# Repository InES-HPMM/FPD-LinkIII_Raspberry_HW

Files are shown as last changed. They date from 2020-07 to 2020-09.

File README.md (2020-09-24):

# FPD-LinkIII_Raspberry_HW

FPD-Link III Hardware compatible with Raspberry Pi Camera and Raspberry Pi CSI connector.

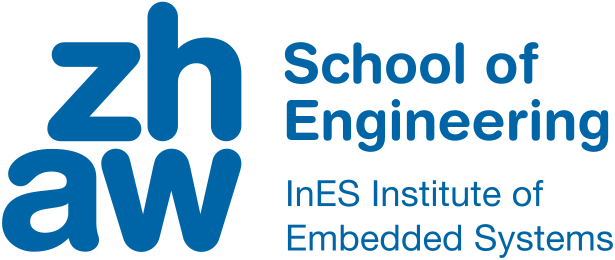
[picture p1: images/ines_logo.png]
(https://www.zhaw.ch/en/engineering/institutes-centres/ines/ "Homepage")


__The group High Performance Multimedia from the Institute of Embedded Systems associated with ZHAW School of Engineering proudly presents a TI FPD-Link III hardware compatible with the Raspberry Pi camera and the Raspberry Pi FFC (FPC, ZIF) camera connector.__

__Additionally we provide an open source driver for TI devices DS90UB954 paired with DS90UB953:__
<https://github.com/InES-HPMM/FPD-LinkIII_ds90ub95x>

> For recent news check out our [Blog](https://blog.zhaw.ch/high-performance/).

## Working Setup

### Overview

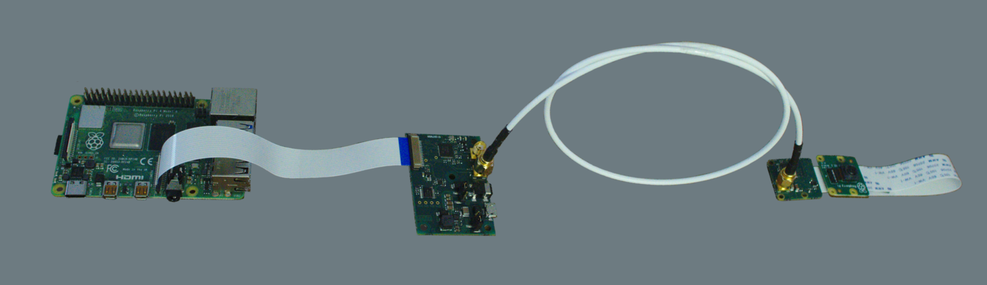
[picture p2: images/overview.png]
Overview


```ditaa
/-------------------\        /----------------------\        /--------------------\        /------------------\
| MIPI CSI RECEIVER |        | FPDLINK DESERIALIZER |        | FPDLINK SERIALIZER |        | MIPI CSI CAMERA  |
+-------------------+  CSI   +----------------------+        +--------------------+  CSI   +------------------+
|                   | <----- |                      |  Coax  |                    | <----- |                  |
| Raspberry Pi (4)  |  GPIO  | fpdlink2raspi        | <----> | piCam2fpdlink      |  GPIO  | Raspberry Pi     |
| Jetson Nano       | <----> | PCB                  |        | PCB                | <----> | Camera Module v2 |
| ...               |   I2C  | DS90UB954            |        | DS90UB953          |   I2C  |                  |
|                   | <----> |                      |        |                    | <----> |                  |
\-------------------/        \----------------------/        \--------------------/        \------------------/
```
 
### fpdlink2raspi PCB

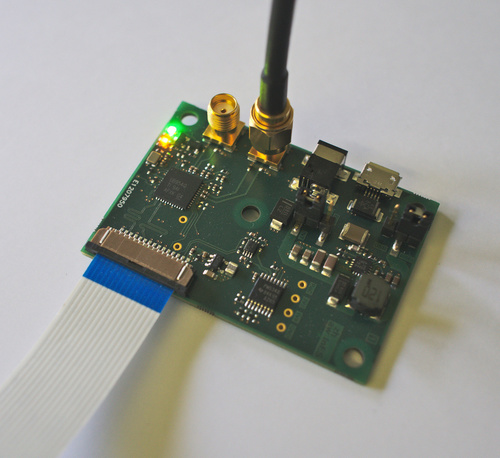
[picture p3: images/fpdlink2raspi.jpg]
fpdlink2raspi PCB

 
### piCam2fpdlink PCB

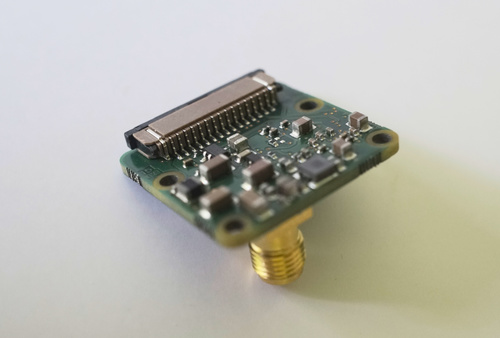
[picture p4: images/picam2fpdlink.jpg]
piCam2fpdlink PCB

 
### Raspberry Pi 4 with MIPI CSI connector

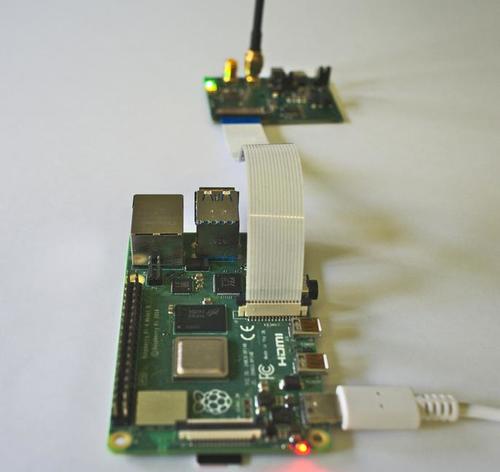
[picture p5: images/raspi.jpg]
RaspberryPi 4


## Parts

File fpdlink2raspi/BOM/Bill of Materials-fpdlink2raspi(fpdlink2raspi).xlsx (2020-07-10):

Name | Description | Designator | Quantity | LibRef | Supplier 1 | Supplier Part Number 1 | Manufacturer 1 | Manufacturer Part Number 1
100n | SMD 100 nF, 50V, X7R, 0402, 10% | C1, C3, C4, C5, C6, C8, C10, C12, C14, C20, C24, C30, C37, C38, C42, C53 | 16 | C0402_100N_X7R_50V_10PCT | Mouser | 81-GCM155R71H104KE2J | Murata | GCM155R71H104KE02J
10n | SMD 10 nF, 16V, X7R, 0402, 10% | C2 | 1 | C0402_010N_X7R_16V_10PCT | Mouser | 81-GRM36X103K16 | Murata | GRM155R71C103KA01D
10u | 10µF, 25V, +/-20%, X5R, 0603 | C7, C9, C11, C13, C23, C29, C51, C52 | 8 | C0603_010U_X5R_25V | Digi-Key | 490-7202-6-ND | Murata | GRM188R61E106MA73D
33n | SMD 33 nF, 50V, X7R, 0402, 10% | C15, C17, C36, C41 | 4 | C0402_033N_X7R_50V_10PCT | Digi-Key | 445-6896-1-ND | TDK | CGA2B3X7R1H333K050BB
15n | SMD 15 nF, 50V, X7R, 0402, 10% | C16, C18 | 2 | C0402_015N_X7R_50V_10PCT | Digi-Key | 445-6894-1-ND | TDK | CGA2B3X7R1H153K050BB
1u | SMD 1 µF, 35V, X5R, 0402, 10% | C19, C27 | 2 | C0402_001U_X5R_35V_10PCT | Digi-Key | 587-6008-1-ND | Taiyo Yuden | GMK105ABJ105KV-F
10n | SMD 10 nF, 50V, X7R, 0402, 10% | C21, C22, C25, C26, C28, C31, C32, C35, C40, C44, C46 | 11 | C0402_010N_X7R_50V_10PCT | Digi-Key | 490-4762-1-ND | Murata | GCM155R71H103KA55D
4u7 | 4.7µF, 25V, +/-10%, X5R, 0603 | C34, C39, C43, C45 | 4 | C0603_04U7_X5R_25V | Digi-Key | 490-7203-1-ND | Murata | GRM188R61E475KE11D
22u | 22µF ±20% 35V Ceramic Capacitor X5R 1206 (3216 Metric) | C47, C48 | 2 | C1206_022U_X5R_35V_20PCT | Digi-Key | 445-8045-1-ND | TDK | C3216X5R1V226M160AC
1u | 1µF ±10% 35V Ceramic Capacitor X7R 0805 (2012 Metric) | C49, C50 | 2 | C0805_001U_X7R_35V_10PCT | Digi-Key | 587-1438-1-ND | Taiyo Yuden | GMK212B7105KG-T
47n | 0.047µF ±10% 16V Ceramic Capacitor X7R 0402 (1005 Metric) | C54 | 1 | C0402_047N_X7R_16V_10PCT | Mouser | 81-GRM155R71C473KA01 | Murata | GRM155R71C473KA01D
3n9 | 3900pF ±5% 50V Ceramic Capacitor C0G, NP0 0603 (1608 Metric) | C55 | 1 | C0603_03N9_C0G_50V_5PCT | Digi-Key | 490-6387-1-ND | Murata | GRM1885C1H392JA01D
220n | 0.22µF ±5% 50V Ceramic Capacitor C0G, NP0 1812 (4532 Metric) | C56 | 1 | C1812_220N_C0G_50V_5PCT | Digi-Key | 445-7892-1-ND | TDK | CGA8R2C0G1H224J320KA
4u7 | SMD 4.7 µF, 10V, X5R, 0402, 20% | C57 | 1 | C0402_04U7_X5R_10V_20PCT | Mouser | 81-GRM155R61A475MEAD | Murata | GRM155R61A475MEAAD
22u | SMD 22 µF, 6.3V, X5R, 0603, 20% | C58 | 1 | C0603_022U_X5R_6V3_20PCT | Digi-Key | 490-13241-1-ND | Murata | GRM186R60J226ME15D
Green, 3.2 V, 140° | WL-SMCD SMD Mono-color Chip LED Diffused, size 0603, Green, 3.2 V, 140° | D1 | 1 | D_WE_150060GS55040 | Mouser | 710-150060GS55040 | Wurth Electronics | 150060GS55040
Yellow, 2 V, 140° | WL-SMCD SMD Mono-color Chip LED Diffused, size 0603, Yellow, 2 V, 140° | D2 | 1 | D_WE_150060YS55040 | Mouser | 710-150060YS55040 | Wurth Electronics | 150060YS55040
SMBJ5.0A | 9.2V Clamp 65.2A Ipp Tvs Diode Surface Mount DO-214AA (SMBJ) | D3 | 1 | D_TVS_5V0_Power | Digi-Key | SMBJ5.0A-E3/52GICT-ND | Vishay Semiconductors | SMBJ5.0A-E3/52
B340LA-13-F | Diode Schottky 40V 3A Surface Mount SMA | D4 | 1 | D_DIODES_B340LA-13-F | Digi-Key | B340LA-FDICT-ND | Diodes | B340LA-13-F
SMBJ24A | 38.9V Clamp 15.5A Ipp Tvs Diode Surface Mount DO-214AA (SMBJ) | D5 | 1 | D_TVS_24V | Digi-Key | SMBJ24ALFCT-ND | Littelfuse | SMBJ24A
SFW15R-1ST | 15 Position FFC, FPC Connector Contacts, Bottom 0.039" (1.00mm) Surface Mount, Right Angle | J1 | 1 | J_PI_CAMV2_BOTTOM | Mouser | 649-SFW15R-1STE1LF | Amphenol ICC | SFW15R-1STE1LF
PJ-075CH-SMT-TR | 1.0 x 3.7 mm, 3.5 A, Horizontal, Surface Mount _SMT_, Shielded, Dc Power Jack Connector | J2 | 1 | J_CUI_PJ-075CH-SMT-TR | Mouser | 490-PJ-075CH-SMT-TR | CUI | PJ-075CH-SMT-TR
Micro USB | WR-COM Micro USB SMT Type B | J3 | 1 | J_WE_629105136821 | Digi-Key | 732-3155-1-ND | Wurth Electronics | 629105136821
10u | LQH3NPZ100MJR SMD Shielded coil, 10 µH, 0.81 A, 0.24 Ω, 30 MHz | L1, L5 | 2 | L1212_SHCOIL_10U_0A81_0R24_20PCT | Arrow | LQH3NPZ100MJRL | Murata | LQH3NPZ100MJRL
1k 0.4A 0.5R | BLM18AG102SN1D SMD Ferrite Bead 1kΩ@100MHz, 25%, 0.4A, DC 500mΩ | L2, L6 | 2 | L0603_BEAD_001K_0A4_25PCT | Mouser | 81-BLM11A102S | Murata | BLM18AG102SN1D
330R 0.7A 280mR | MPZ1005S331ETD25 SMD Ferrite Bead 330Ω@100MHz ±25%, 700 mA, DC 280 mΩ | L3, L7 | 2 | L0402_BEAD_330R_0A7_25PCT | Mouser | 810-MPZ1005S331ETD25 | TDK | MPZ1005S331ETD25
47R 0.45A 450mR | MPZ1005F470ETD25 SMD Ferrite Bead 47Ω@100MHz ±25%, 450 mA, DC 450 mΩ | L4, L8 | 2 | L0402_BEAD_047R_0A45_25PCT | Mouser | 810-MPZ1005F470ETD25 | TDK | MPZ1005F470ETD25
120R 3A 25mR | BLM18SG121TN1D SMD Ferrite Bead 120Ω@100MHz, 25%, 3A, DC 25mΩ | L9, L10, L11, L12 | 4 | L0603_BEAD_120R_3A_25PCT | Mouser | 81-BLM18SG121TN1D | Murata | BLM18SG121TN1D
12uH, 2.6A | WE-LQS SMT Power Inductor, size 6045, 12uH, 2.6A | L13 | 1 | L_WE_74404064120 | Digi-Key | 732-5551-1-ND | Wurth Electronics | 74404064120
2u2 | DFE201210U-2R2M=P2 SMD Shielded coil, 2.2 µH ±20%, 1.2 A, 0.228 Ω | L14 | 1 | L0805_SHCOIL_2U2_1A2_R228_20PCT | Mouser | 81-DFE201612E-2R2MP2 | Murata | DFE201612E-2R2M=P2
QPC02SXGN-RC | 2 (1 x 2) Position Shunt Connector Black Open Top 0.100" (2.54mm) Gold | M1, M2 | 2 | M_JUMPER_2.54 | Digi-Key | S9337-ND | Sullins | QPC02SXGN-RC
BSS138-13-F | N-Channel Digital FET 50V, 0.2A, 3.5Ω | Q1, Q2 | 2 | Q_DIODES_BSS138-13-F | Mouser | 621-BSS138-13-F | Diodes | BSS138-13-F
0R | SMD 0 Ω, 0402, 1.5 A, 20 mΩ Rmax | R1, R18, R19, R26, R35, R36, R37, R41, R43 | 9 | R0402_000R_1A5_0R02 | Mouser | 71-CRCW0402-0-E3 | Vishay | CRCW04020000Z0ED
10k | SMD 10 kΩ, 1%, 50V, 0402, 1/16W, ±100ppm | R2, R3, R32, R42 | 4 | R0402_010K_50V_0W063_100PPM | Mouser | 71-CRCW0402-10K-E3 | Vishay | CRCW040210K0FKED
1k | SMD 1 kΩ, 0.1%, 50V, 0402, 1/16W, ±25ppm | R7, R8, R9 | 3 | R0402_001K_50V_0W063_25PPM_0PCT1 | Digi-Key | P1.0KDCCT-ND | Panasonic | ERA-2AEB102X
4k7 | SMD 4.7 kΩ, 1%, 50V, 0402, 1/16W, ±100ppm | R10, R11, R25 | 3 | R0402_04K7_50V_0W063_100PPM | Digi-Key | 541-4.70KLCT-ND | Vishay | CRCW04024K70FKED
47k | SMD 47 kΩ, 1%, 50V, 0402, 1/16W, ±100ppm | R12, R13, R33, R34 | 4 | R0402_047K_50V_0W063_100PPM | Mouser | 71-CRCW0402-47K-E3 | Vishay | CRCW040247K0FKED
1k | SMD 1 kΩ, 0.1%, 50V, 0402, 1/16W, ±25ppm | R14 | 1 | R0402_001K_50V_0W063_100PPM | Digi-Key | 541-1.00KLDKR-ND | Vishay Dale | CRCW04021K00FKED
1k2 | SMD 1.2 kΩ, 1%, 50V, 0402, 1/16W, ±100ppm | R15 | 1 | R0402_01K2_50V_0W063_100PPM | Digi-Key | 541-1.20KLCT-ND | Vishay | CRCW04021K20FKED
390R | SMD 390 Ω, 1%, 50V, 0402, 1/16W, ±100ppm | R16 | 1 | R0402_390R_50V_0W063_100PPM | Digi-Key | 541-390LCT-ND | Vishay | CRCW0402390RFKED
4k02 | SMD 4.02 kΩ, 1%, 75V, 0603, 1/10W, ±100ppm | R17, R22 | 2 | R0603_4K02_75V_0W100_100PPM | Digi-Key | 541-4.02KHCT-ND | Vishay | CRCW06034K02FKEA
118k | SMD 118 kΩ, 1%, 50V, 0402, 1/16W, ±100ppm | R20, R21 | 2 | R0402_118K_50V_0W063_100PPM | Digi-Key | 541-118KLCT-ND | Vishay | CRCW0402118KFKED
49R9 | SMD 49.9 Ω, 1%, 50V, 0402, 1/16W, ±100ppm | R23, R24 | 2 | R0402_49R9_50V_0W063_100PPM | Mouser | 71-CRCW0402-49.9-E3 | Vishay | CRCW040249R9FKED
78k7 | SMD 78.7 kΩ, 1%, 50V, 0402, 1/16W, ±100ppm | R28 | 1 | R0402_78K7_50V_0W063_100PPM | Digi-Key | 541-78.7KLCT-ND | Vishay | CRCW040278K7FKED
100R | SMD 100 Ω, 1%, 50V, 0402, 1/16W, ±100ppm | R30 | 1 | R0402_100R_50V_0W063_100PPM | Digi-Key | 541-100LCT-ND | Vishay Dale | CRCW0402100RFKED
97k6 | SMD 97.6 kΩ, 1%, 50V, 0402, 1/16W, ±100ppm | R31 | 1 | R0402_97K6_50V_0W063_100PPM | Mouser | 71-CRCW0402-97.6K-E3 | Vishay | CRCW040297K6FKED
187k | SMD 187 kΩ, 1%, 50V, 0402, 1/16W, ±100ppm | R38 | 1 | R0402_187K_50V_0W063_100PPM | Mouser | 71-CRCW0402-187K-E3 | Vishay | CRCW0402187KFKED
1k54 | 1.54 kOhms ±1% 0.063W, 1/16W Chip Resistor 0402 (1005 Metric) Automotive AEC-Q200 Thick Film | R39 | 1 | R0402_1K54_50V_0W063_100PPM | Digi-Key | 541-1.54KLCT-ND | Vishay | CRCW04021K54FKED
60k4 | 60.4 kOhms ±1% 0.063W, 1/16W Chip Resistor 0402 (1005 Metric) Automotive AEC-Q200 Thick Film | R40 | 1 | R0402_60K4_50V_0W063_100PPM | Digi-Key | 541-60.4KLCT-ND | Vishay | CRCW040260K4FKED
TCA9534APW | TCA9534A Low Voltage 8-Bit I2C and SMBUS Low-Power I/O Expander With Interrupt Output and Configuration Registers | U1 | 1 | U_TI_TCA9534APW | Digi-Key | 296-40573-1-ND | Texas Instruments | TCA9534APWR
TCA9406DCUR | TCA9406 Dual Bidirectional 1-MHz I2C-BUS and SMBus Voltage Level-Translator, 1.65 to 3.6 V, -40 to 85 degC, 8-pin US8 (DCU), Green (RoHS & no Sb/Br) | U2 | 1 | U_TI_TCA9406DCUR | Digi-Key | 296-28109-6-ND | Texas Instruments | TCA9406DCUR
DS90UB954TRGZxQ1 | DS90UB954-Q1 Dual 4.16 Gbps FPD-Link III Deserializer Hub With MIPI CSI-2 Outputs for 2MP/60fps Cameras and RADAR | U3 | 1 | U_TI_DS90UB954-Q1 | Digi-Key | 296-48292-1-ND | Texas Instruments | DS90UB954TRGZRQ1
TPS55340RTE | Integrated 5-A Wide Input Range Boost/SEPIC/Flyback DC/DC Regulator | U4 | 1 | U_TI_TPS55340RTE | Digi-Key | 296-30530-1-ND | Texas Instruments | TPS55340RTET
LM3671MFX-1.8/NOPB | LM3671/-Q1 2-MHz, 600-mA Step-Down DC-DC Converter | U5 | 1 | U_TI_LM3671MFX-1.8 | Digi-Key | 296-41425-1-ND | TI National Semiconductor | LM3671MFX-1.8/NOPB
SMA JACK STR | SMA Connector Jack, Female Socket 50Ohm Surface Mount Solder (PN: 0732511350) | X1, X2 | 2 | X_MOLEX_0732511350 | Mouser | 538-73251-1350 | Molex | 73251-1350
1241150-3 | Connector Header Through Hole 3 position 0.100" (2.54mm) | X3, X4 | 2 | J_3x1_2.54mm_header_SMD | Mouser | 571-1241150-3 | AMP - TE CONNECTIVITY | 1241150-3
SG-210STF 25.0000M | Crystal Oscillator 25 MHz, ±50 ppm | Y1 | 1 | Y_SG-210STF25.0000M | Mouser | 732-SG210STF25.Y3 | Epson | SG-210STF 25.0000MY3

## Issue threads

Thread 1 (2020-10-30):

PCB

shahbazaly, 2020-10-30:
Hello, I have tried to get a PCB of piCam2fpdlink made from a company. I got a response from them about the polarity of u1, u2 and u3 components. Ca you tell me the correct polarity of these components so that the company could get it made for me ? Please see the attachment. Thank you.

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

dariis, 2020-10-30:
On page 5 of the pdf the correct polarities of U1 and U2 are marked:
https://github.com/InES-HPMM/FPD-LinkIII_Raspberry_HW/blob/master/piCam2fpdlink/piCam2fpdlink_PCB_0v5.PDF

The U3 the polarity is missing, thanks for pointing that out:
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

shahbazaly, 2020-10-31:
Thank you very much

Closed 2020-10-31.

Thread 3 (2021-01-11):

Raspberry Pi I2C clock stretching

sdev1, 2021-01-11:
Hello! I have a question about I2C clock stretching, that Deserializer require from I2C Master.

From DS90UB954-Q1 manual:
_The Bidirectional control channel provides a mechanism to read or write I2C registers in remote devices over the FPD-Link III interface. **The I2C Master located at the Deserializer must support I2C clock stretching.** Accesses to serializer or remote slave devices over the Bidirectional Control Channel will result in clock stretching to allow for response time across the link. The DS90UB954-Q1 acts as an I2C slave on the local bus, forwards read and writere quests to the remote device, and returns the response from the remote device to the local I2C bus. To allow for the propagation and regeneration of the I2C transaction at the remote device, the DS90UB954-Q1 will stretch the I2C clock while waiting for the remote response._

As i know, Raspberry Pi 4 hardware (like other Pi's) does not support clock stretching by default, only if the i2c-gpio overlay is used. The question is, how does the FPD-LinkIII_Raspberry_HW properly work then?

sdev1, 2021-01-15:
Any answers?

JanaUnderground, 2021-01-15:
In our setup with the Raspberrypi 4 and the FPD-LinkIII_Raspberry_HW we did not experience any problems with the i2c. We will make some measurements of the i2c lines as soon as possible. To check if that is because the clock stretching is not occuring or if the i2c hardware of the RaspberryPi 4 is handling the clock stretching correctly.

We will keep you posted.

sdev1, 2021-01-15:
Ok, thank you.

Closed 2023-08-21.

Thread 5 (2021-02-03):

Special driver needed and virtual channel

loopy83, 2021-02-03:
Hi,

first of all - VERY interesting project! Thank you very much!

I have two questions:
> 1. I have a "special TOF camera module " which requires a specific camera driver to run on the RPI. Can I just reuse this driver, or is any special driver for the ds90ub95x needed? I saw your driver here: https://github.com/InES-HPMM/FPD-LinkIII_ds90ub95x
> So will the ds90ub95x behave like its own camera, or will it behave like the original camera?

> 2. Does this setup support Virtual Channel in MIPI?

Thank you very much!

JanaUnderground, 2021-03-17:
Hi,
Sorry for the late answer. Very happy to hear you like the project.

1. The ds90ub95x driver makes a transparent link. This means after the driver has run, the camera behaves like the original camera. In our example with the imx219 sensor, after the ds90ub95x driver has run, the imx219 driver can be run unchanged. The most important point is that while booting the ds90 driver needs to be run before the camera driver.

2. The ds90ub954 deserializer supports virtual channel. So should our driver, however this could not be tested. Not sure if the Raspberry Pi can handle virtual channels.

Closed 2021-05-19.

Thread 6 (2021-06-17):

Can this be used to output DSI to FPD-LinkIII for automotive displays?

patfelst, 2021-06-17:
Hi there, could this be adapted essentially in reverse so the RPi can output video on DSI connector, to FPD-LinkIII format to display RPi on an automotive display, e.g. BMW which uses a FAKRA 4-pin interface?

Thanks.

JanaUnderground, 2021-06-23:
Hi,
Unfortunately, I don't think this will work even though both protocols are quite similar. TI does offer seperate chips for DSI applications: https://www.ti.com/interface/fpd-link-serdes/display-serdes/overview.html

patfelst, 2021-06-25:
Thanks I'll look into those TI chips.

Closed 2021-06-25.

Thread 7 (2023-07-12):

Guidance on Libcamera-qcam step

Etherity, 2023-07-12:
Hello,

Thank you for sharing this project on github. I've tried following your steps to get my board up and running and there are some issues with the IMX219 sensor not registering. I've attached a picture at the step I'm having trouble with along with the error message for the IMX219. Is there any assistance you could provide me?

I've tried both buster and bullseye but had the same issues pop up.

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

MichaelWaespe1, 2023-09-04:
Hi @Etherity

We have made a new release for kernel version 6.1 on the driver repository https://github.com/InES-HPMM/FPD-LinkIII_ds90ub95x. Please try again and don't hesitate to raise the issue again if the problems persist.

Closed 2023-09-04.

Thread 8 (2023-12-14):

can you help me change the SMA port to fakra?

fancong5201314, 2023-12-14:
I am a hardware novice, and there is no PCB diagram in the hardware information provided. Can you help me change the SMA port to fakra port?
Thanks a lot.

MichaelWaespe1, 2024-01-23:
Hello @fancong5201314
If you are interested in the schematic and PCB files, please contact me directly at:
waep"at"zhaw.ch

MichaelWaespe1, 2024-01-23:
Hello @fancong5201314
If you are interested in the schematic and PCB files, please contact me directly at:
waep"at"zhaw.ch

Closed 2024-01-23.

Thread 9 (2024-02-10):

Raspberry Pi Camera v3 support

jess-sys, 2024-02-10:
Hi,

Thank you for this amazing work.

By any chance, is this project compatible with the newer RPi Camera v3 model ?

Thanks,

—
Jessy

MichaelWaespe1, 2024-02-22:
Hi @jess-sys

The hardware also supports the Raspi camera module v3. Please also have a look at our driver repository, where we have recently made a release that supports the Raspi Cam V3.

Best regards
Michael

Closed 2024-02-22.

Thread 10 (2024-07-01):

Way to buy these boards?

lucasriepe, 2024-07-01:
Where did you produce these boards?
or is there any way to buy these boards?

MichaelWaespe1, 2024-07-12:
Hi @lucasriepe

You can order these PCBs from any reputable manufacturer with the Gerber files. However, we do not sell the PCBs.

Best regards,
Michael

lucasriepe, 2024-07-12:
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

first of all, thank you very much for answering! Where did you have yours built? because I can use the gerber but not the BOM or the pick and place

MichaelWaespe1, 2024-07-16:
Hi @lucasriepe

In which file types do you need the BOM and Pick and Place? I can recreate them for you in your preferred format.

Best regards,
Michael

Closed 2024-08-06.

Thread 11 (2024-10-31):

Schematic clarification

pauleffect90, 2024-10-31:
Hello. First of all, thanks for posting this project. It's very interesting.

Id like to ask why did you use TCA9534APW on the Des?
From what I gleamed, the Ser uses GPIO0 (as the enable pin for the Pi Camera). And that's about it.

Did you by any chance place it there following the holy water principle (it won't do you any good, but it won't hurt either)?

Thanks a million!

MichaelWaespe1, 2025-02-07:
Hi

Sorry for the late reply. The enable for the raspi cam is done directly via the enable of the CSI connector (over FPD-Link). The GPIO expander is there to enable the Des and for general use of GPIO. For example, if you want to make a new Ser hardware that needs more GPIO interfacing, you do not need to redo the Des PCB.

Best regards,
Michael

Closed 2025-02-07.

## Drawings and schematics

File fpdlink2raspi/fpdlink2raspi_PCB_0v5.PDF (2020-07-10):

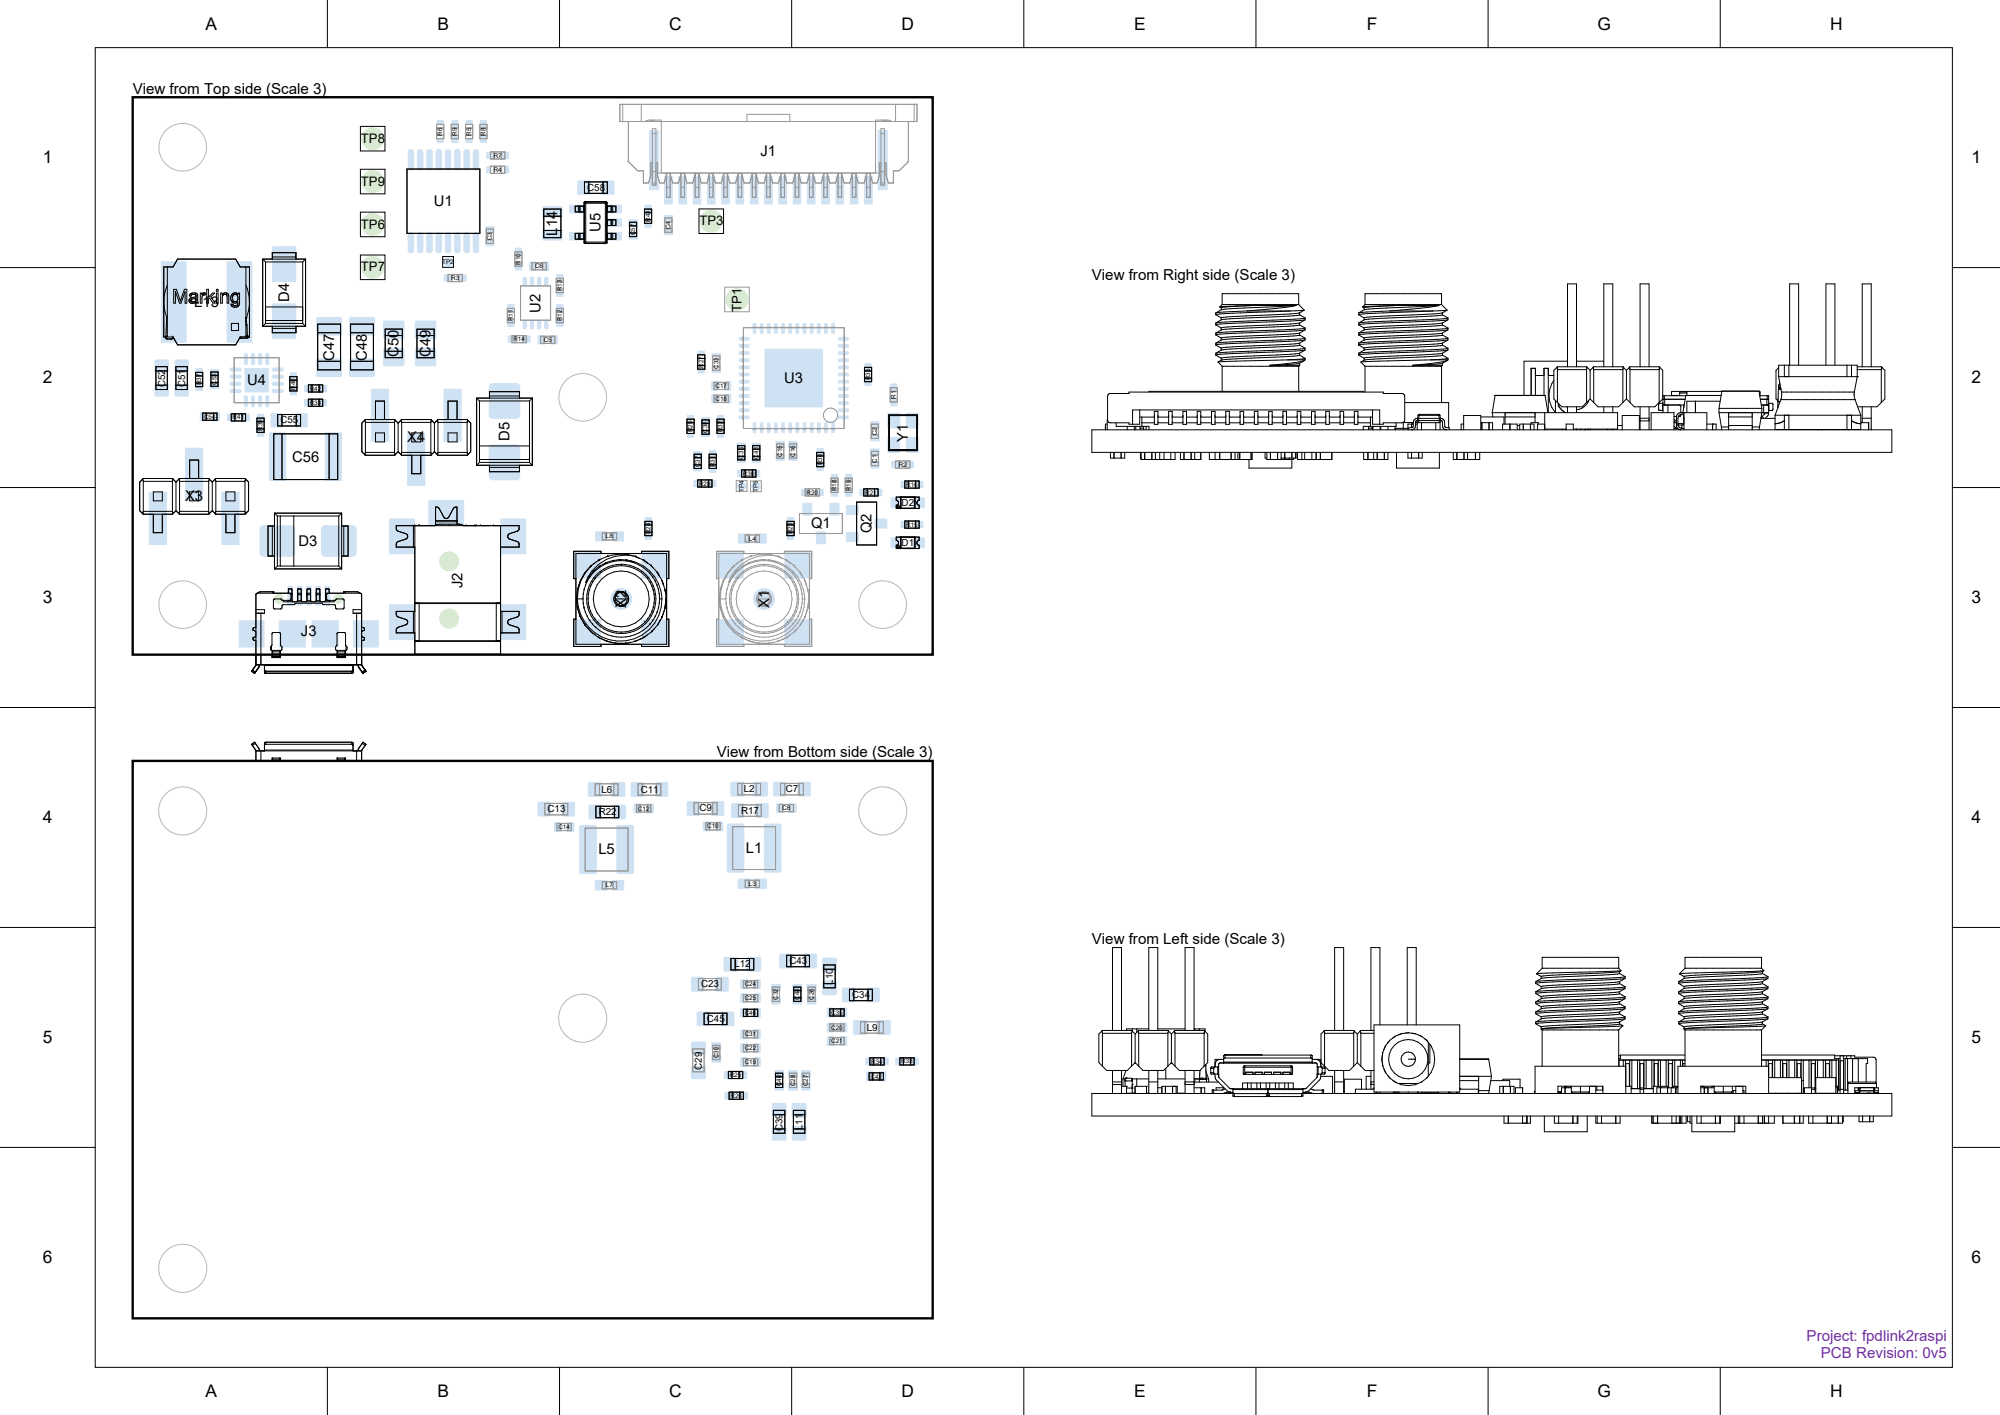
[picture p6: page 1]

View from Top side (Scale 3)

View from Right side (Scale 3)

View from Bottom side (Scale 3)

View from Left side (Scale 3)

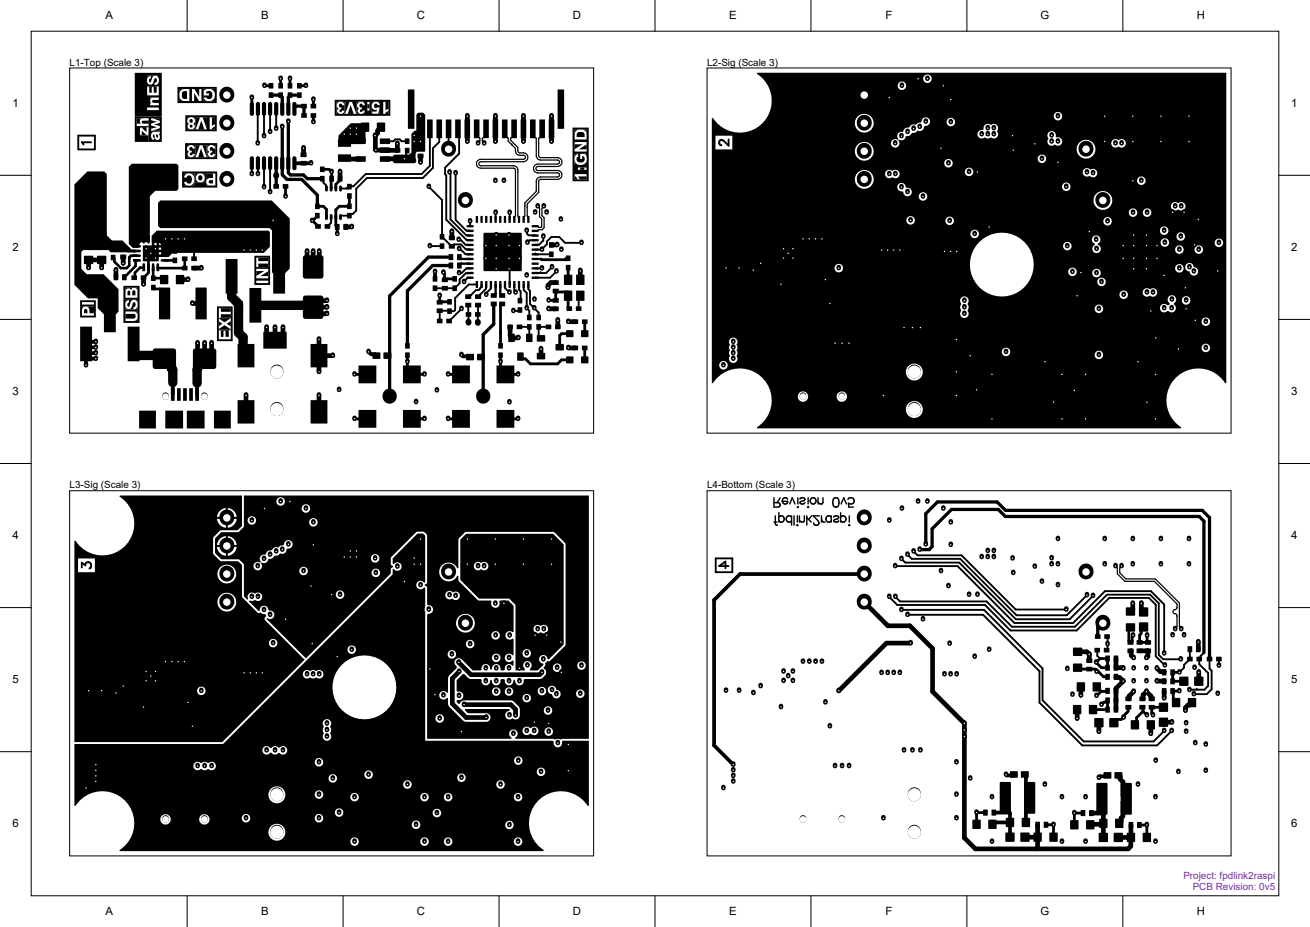
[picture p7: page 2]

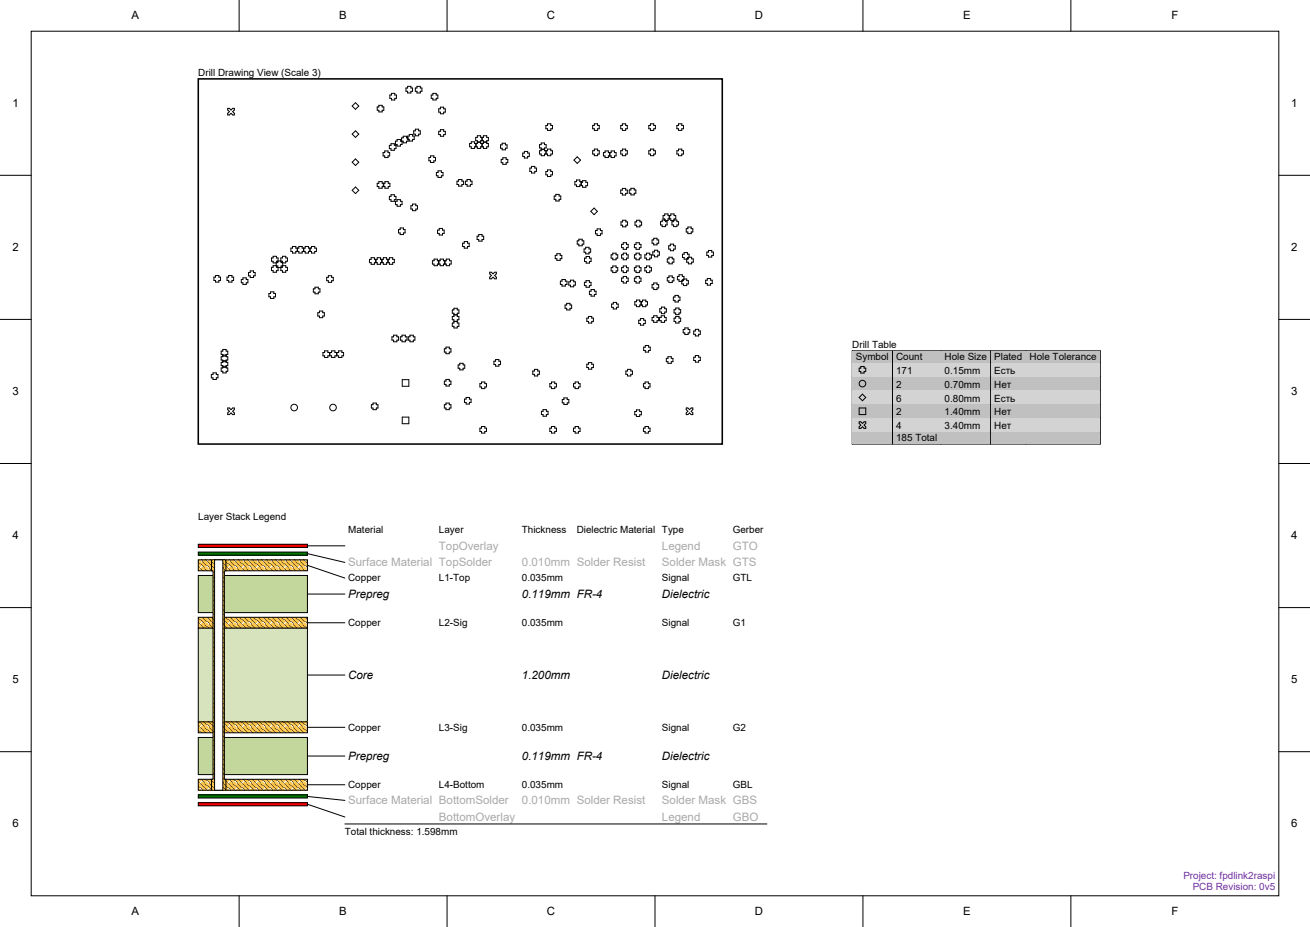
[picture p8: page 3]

Drill Drawing View (Scale 3)

Symbol | Count | Hole Size | Plated | Hole Tolerance

171 | 0.15mm | Есть
2 | 0.70mm | Нет
6 | 0.80mm | Есть
2 | 1.40mm | Нет
4 | 3.40mm | Нет
185 Total

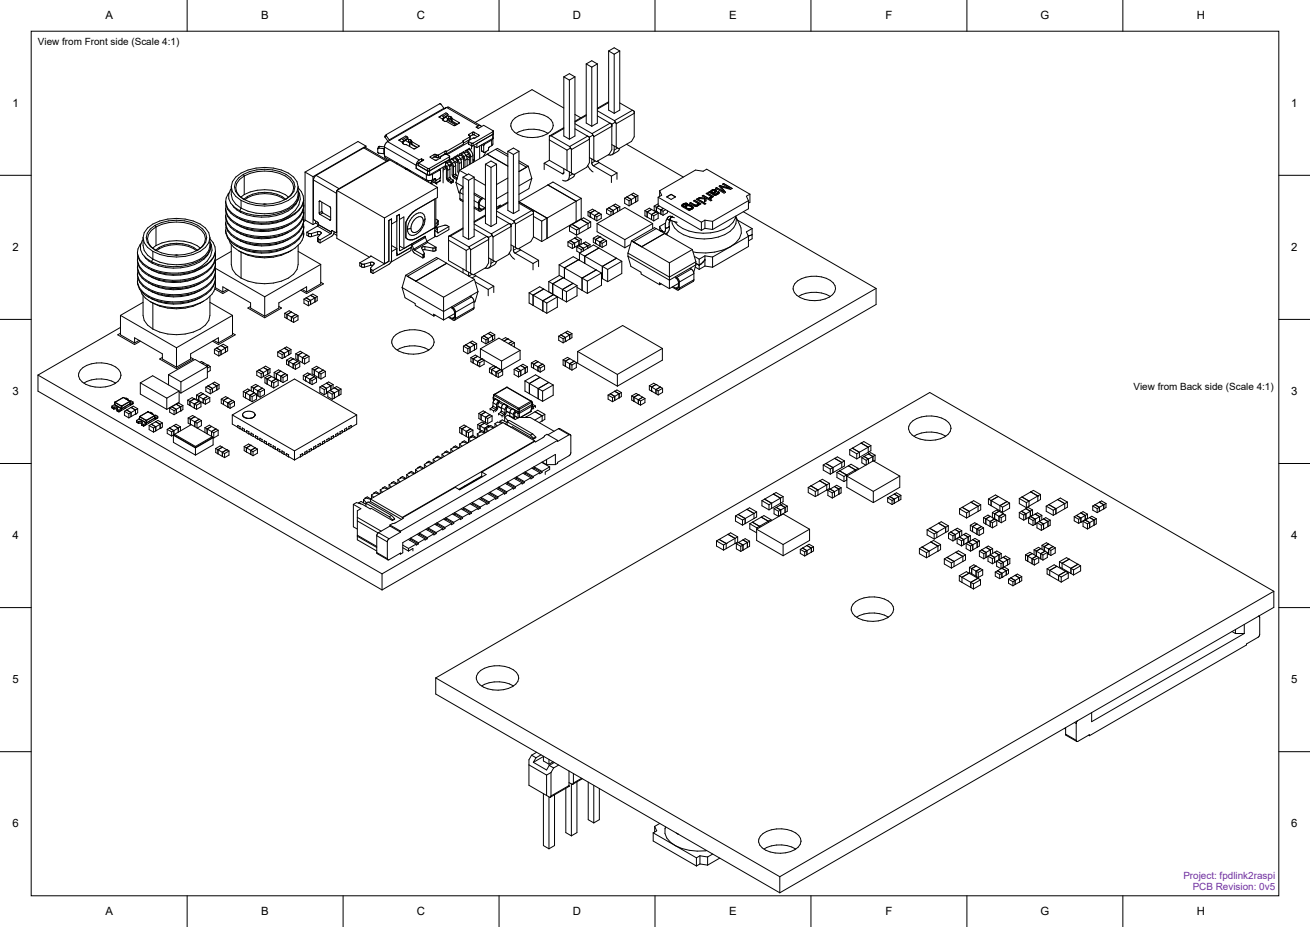
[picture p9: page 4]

View from Front side (Scale 4:1)

View from Back side (Scale 4:1)

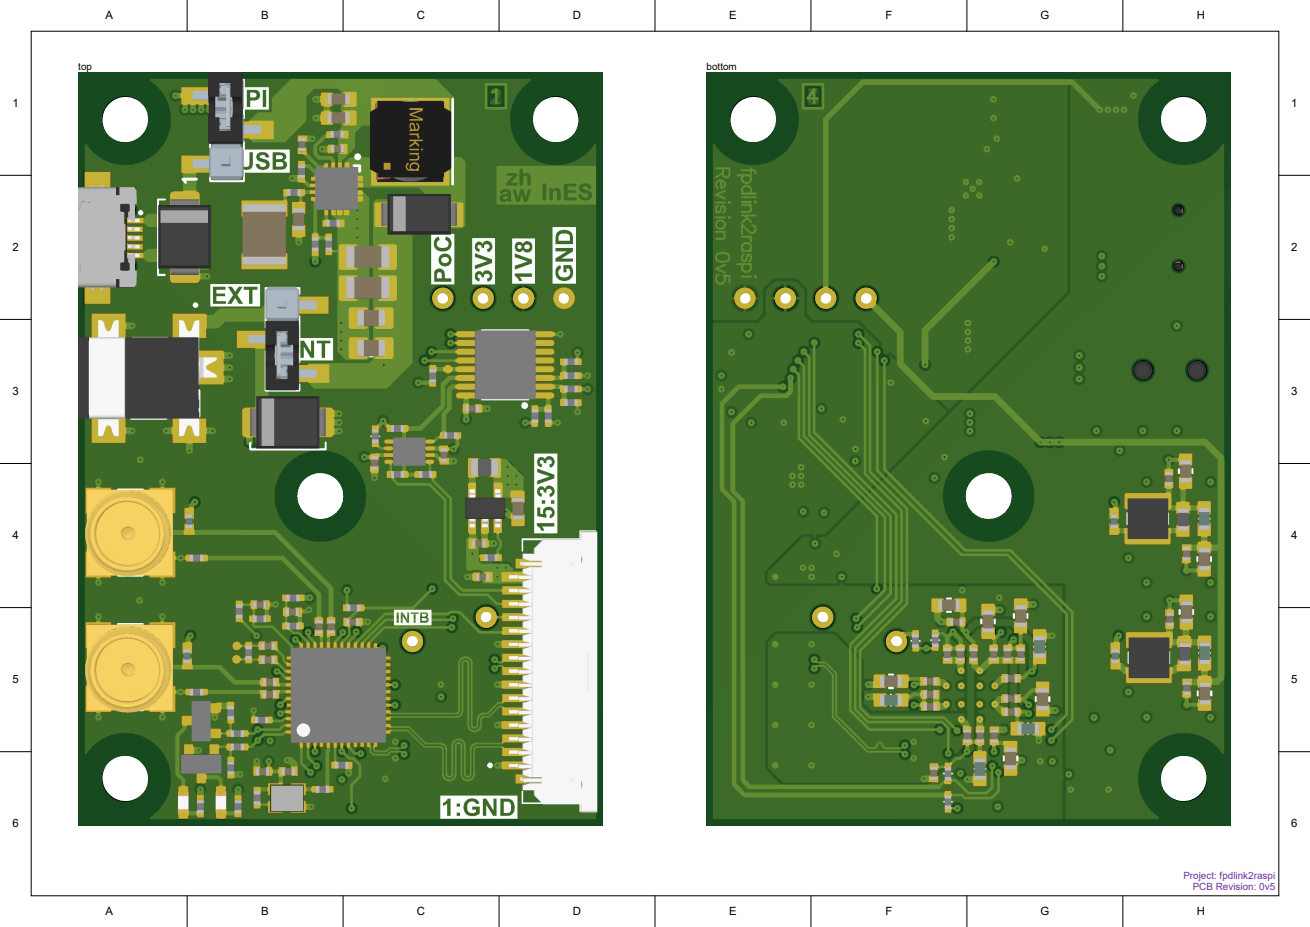
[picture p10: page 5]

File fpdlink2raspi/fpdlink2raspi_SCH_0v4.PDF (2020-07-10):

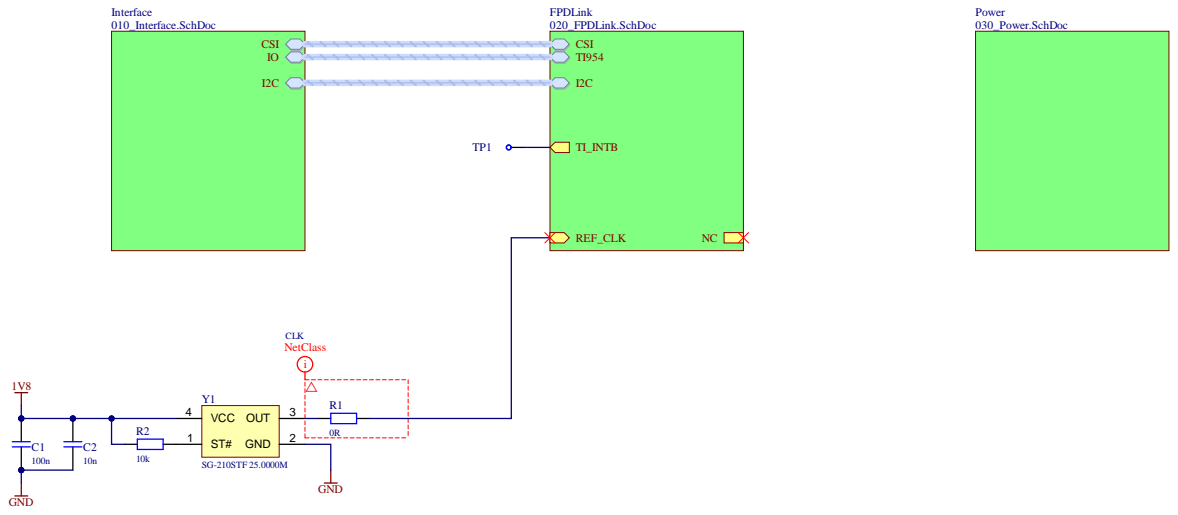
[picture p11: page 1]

Rev | Date | Sign | Release Notes
0v0 0v1 0v2 0v3 0v4 | 22.04.20 27.04.20 29.04.20 29.04.20 05.05.20 | gana gana gana gana gana | Imported Project, first draft. Review release. Clean up. Fix library error. L1, L5 (10uH PoC) wrong footprint.

Zurich University of Applied Sciences
InES - Institute of Embedded Systems
PO Box 805
8041 Winterthur
Switzerland

This document is property of InES - Institute of Embedded Systems

Title
FPDLink III to MIPI

Size A3 | Document Number | Revision 0v4

Sheet 1 of 4 | Print date: 10.07.2020 | Drawn by: gana

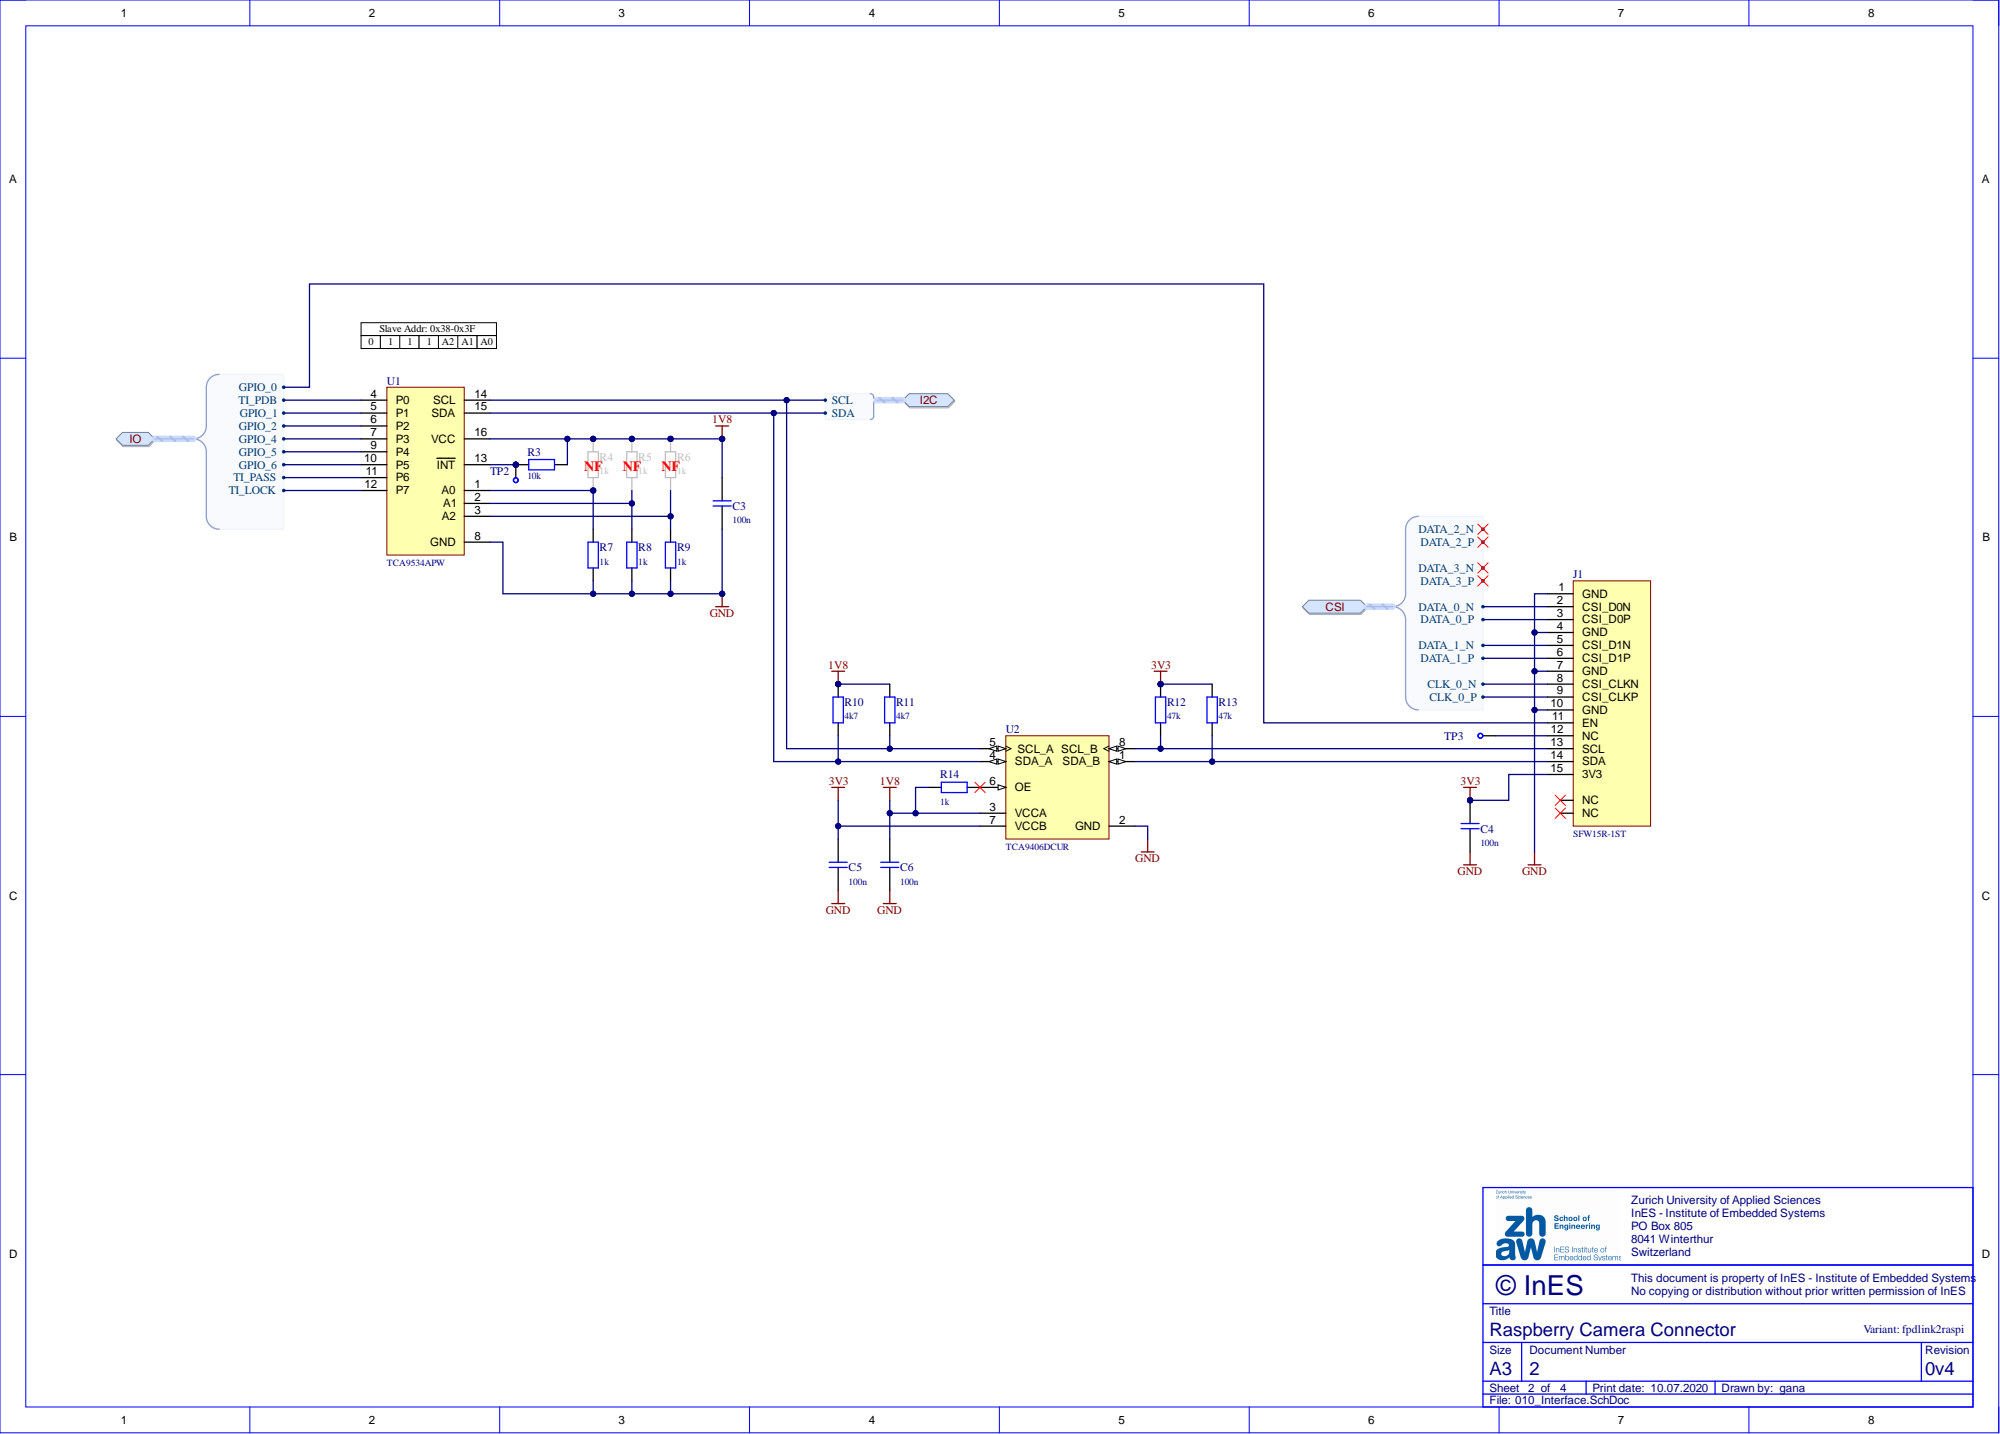
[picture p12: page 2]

y of Applied Sciences
titute of Embedded Sy
Ins

This document is propert

writ

Siz e | Document Number | Revisio n v

Shee t 2 of | Print date: 10.07.20 | Drawn by : gana

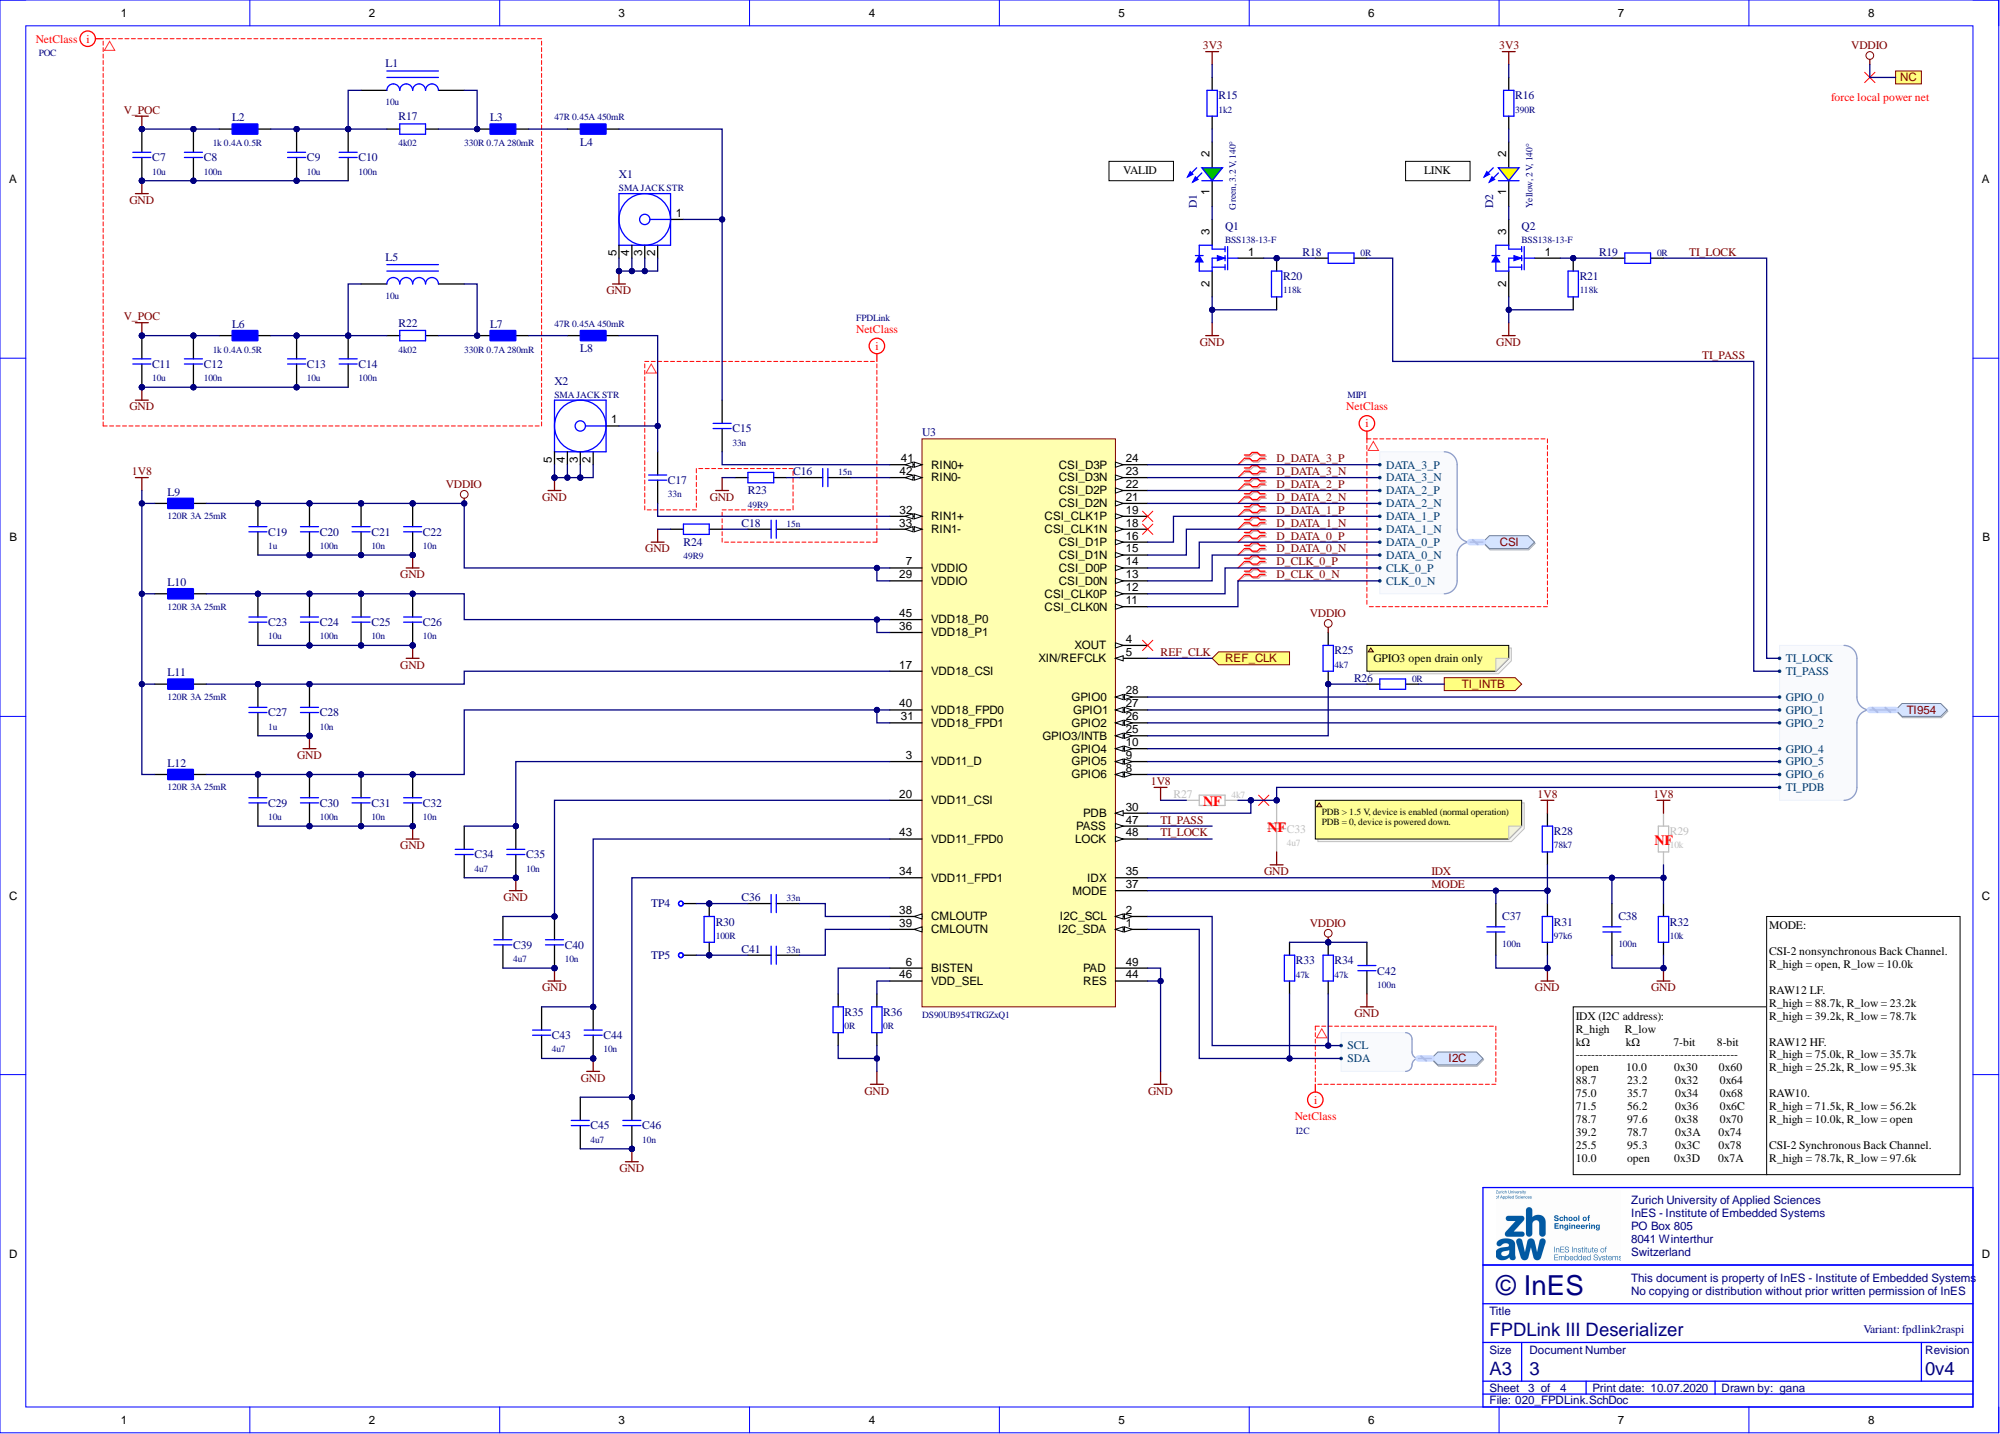
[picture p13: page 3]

D _ D ATA_ 0 _ N
D _CL K_ 0 _ P
D _CL K_ 0 _ N

y of Applied Sciences
titute of Embedded Sy
Ins

This document is propert

writ

Siz e | Document Number | Revisio n v

Shee t 3 of | Print date: 10.07.20 | Drawn by : gana

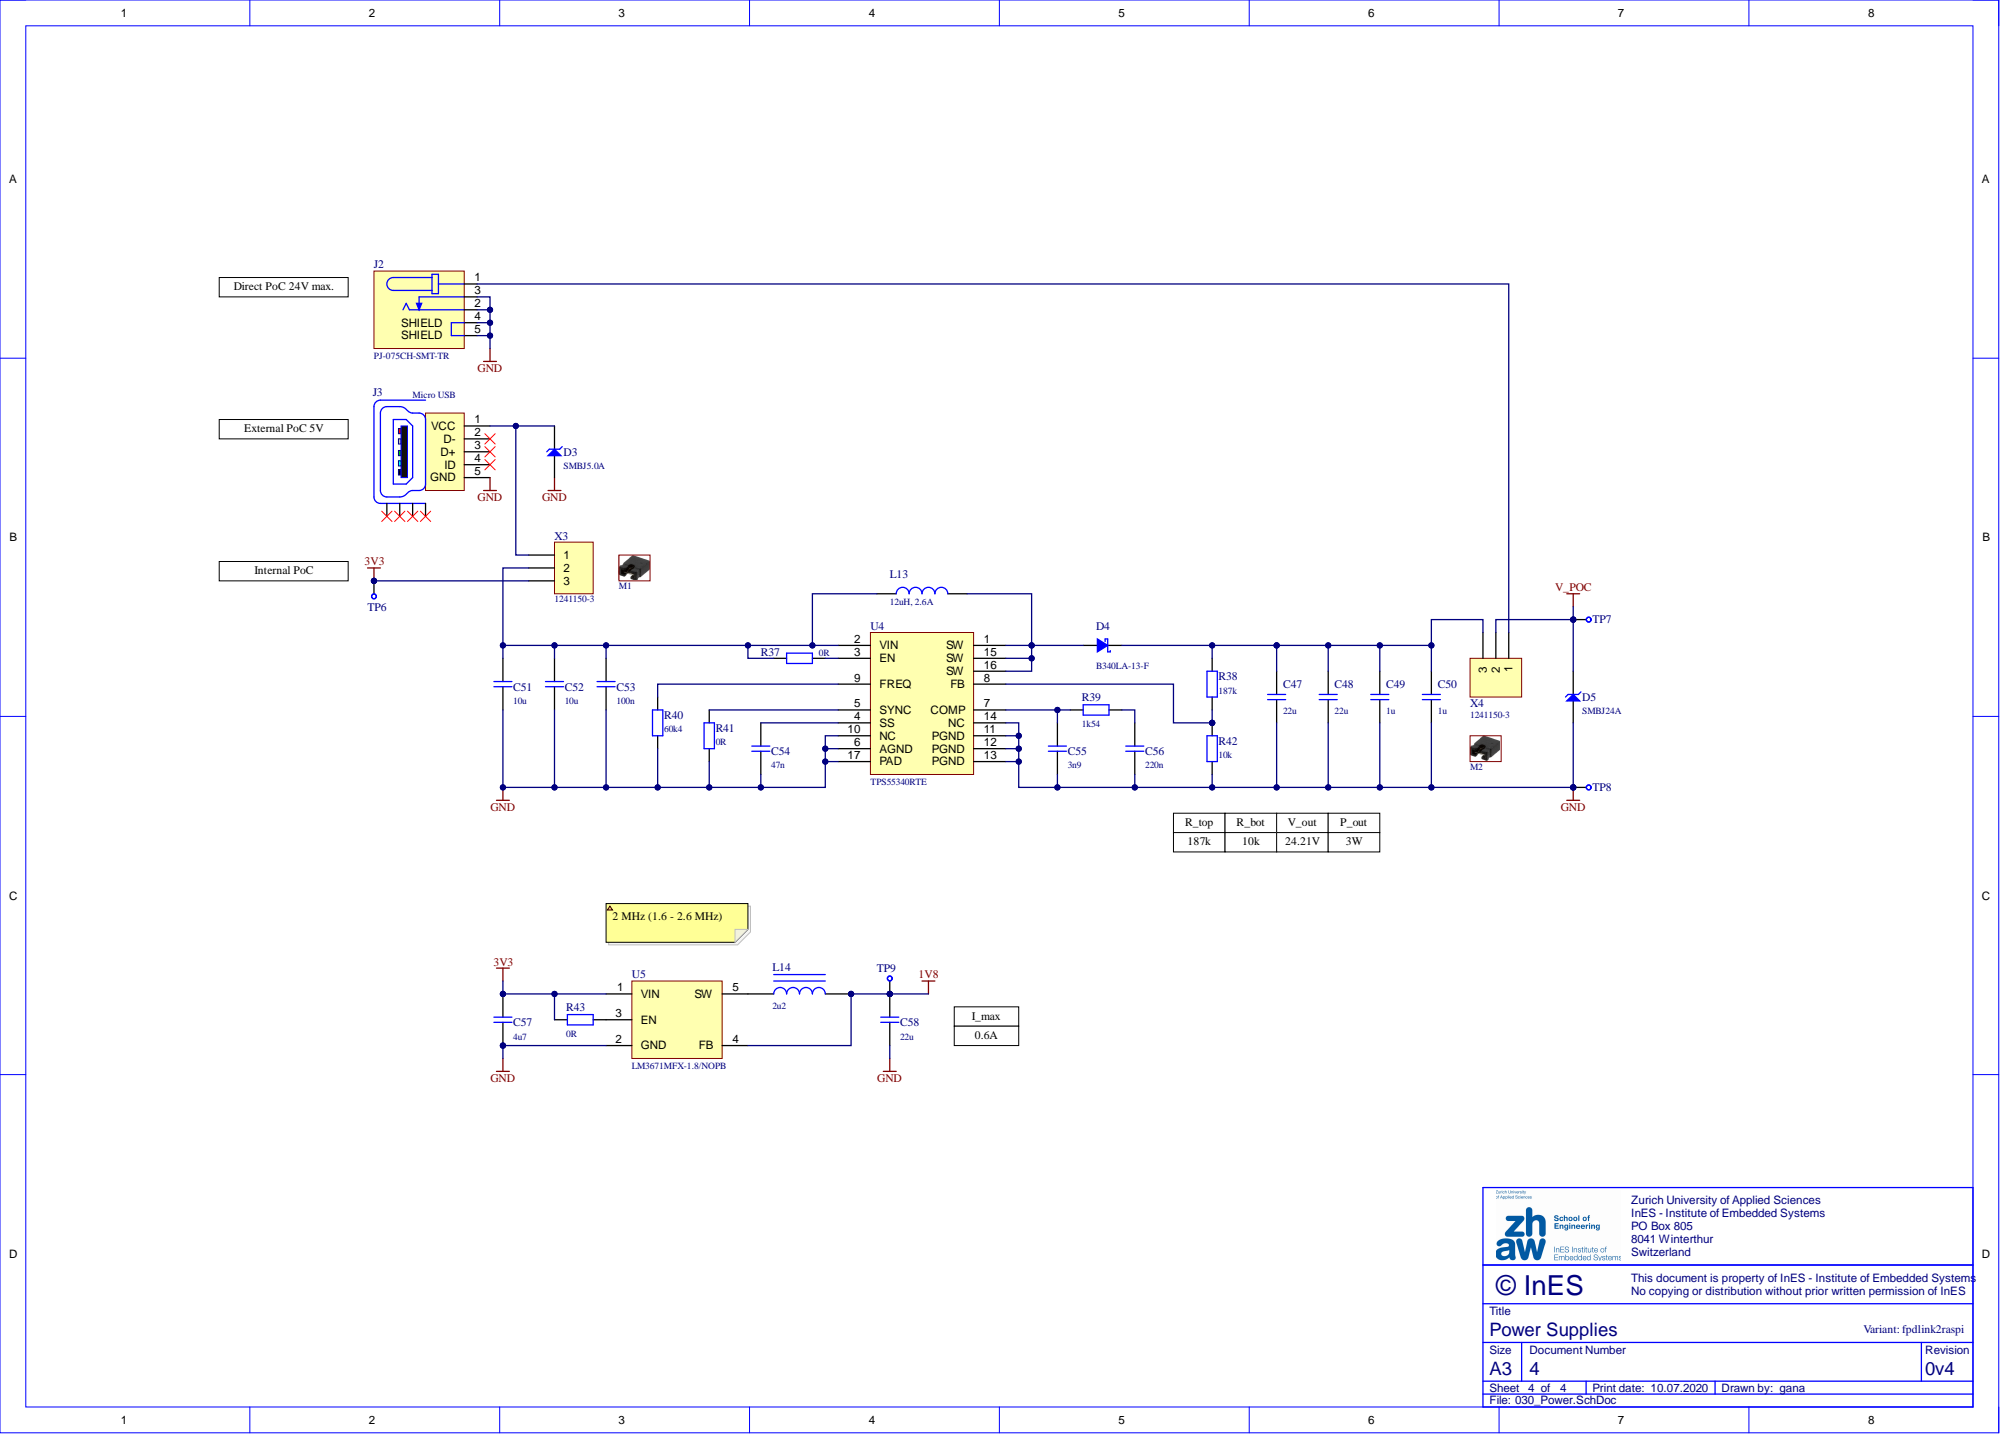
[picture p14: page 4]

R_top | R_bot | V_out | P_out
187k | 10k | 24.21V | 3W

Zurich University of Applied Sciences
InES - Institute of Embedded Systems
PO Box 805
8041 Winterthur
Switzerland

This document is property of InES - Institute of Embedded Systems

Size | Document Number | Revision 0v4

Sheet 4 of 4 | Print date: 10.07.2020 | Drawn by: gana

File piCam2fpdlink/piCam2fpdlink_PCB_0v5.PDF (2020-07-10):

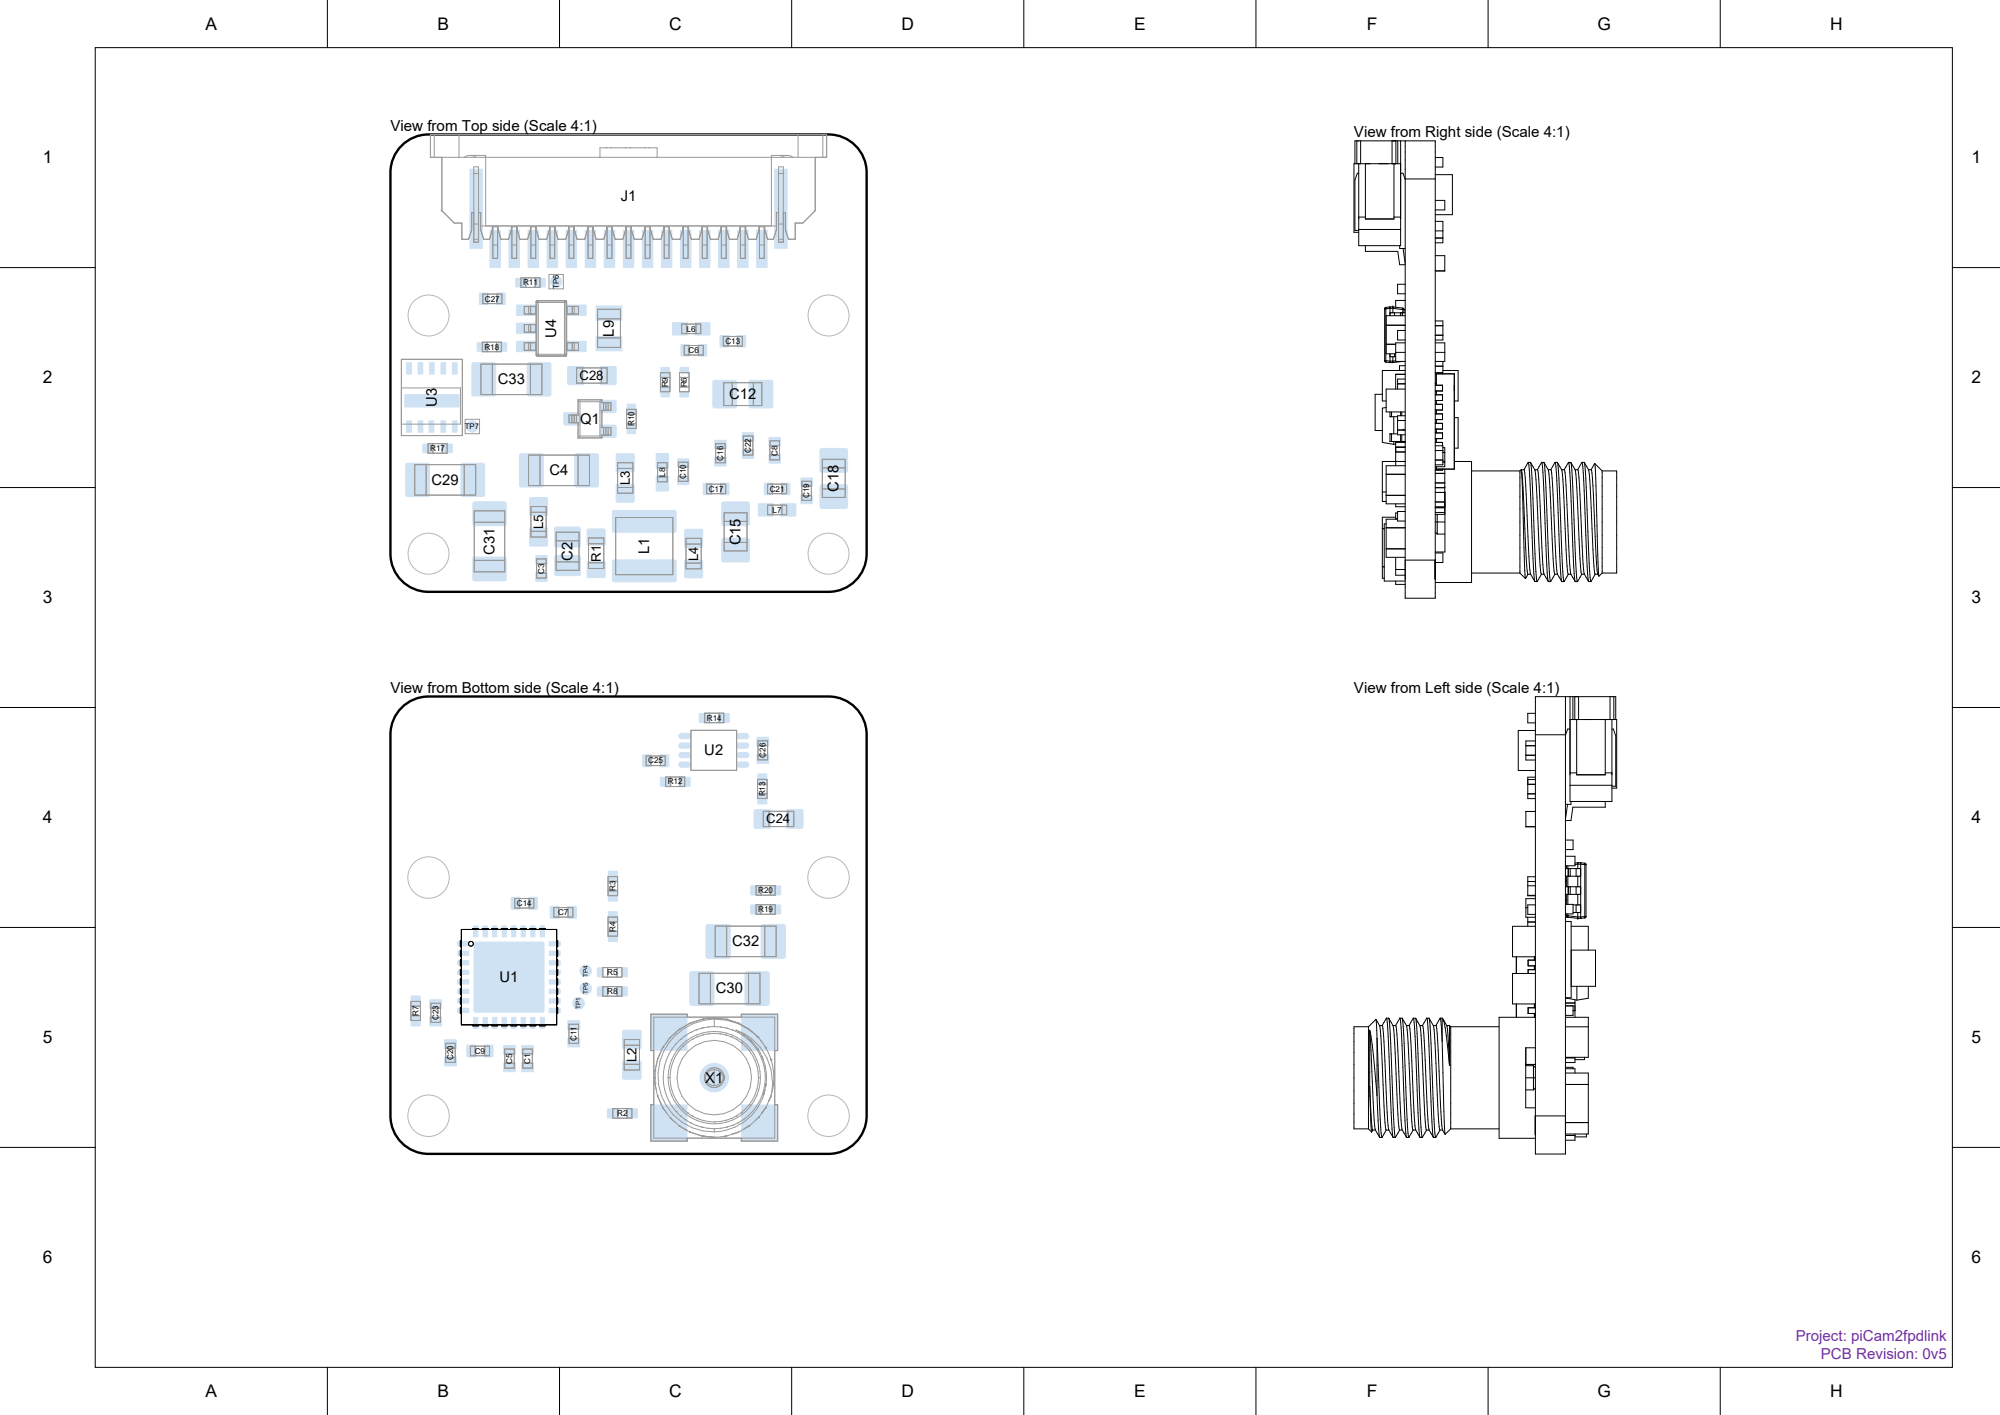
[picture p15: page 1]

View from Top side (Scale 4:1) R7

View from Right side (Scale 4:1)

View from Bottom side (Scale 4:1)

View from Left side (Scale 4:1)

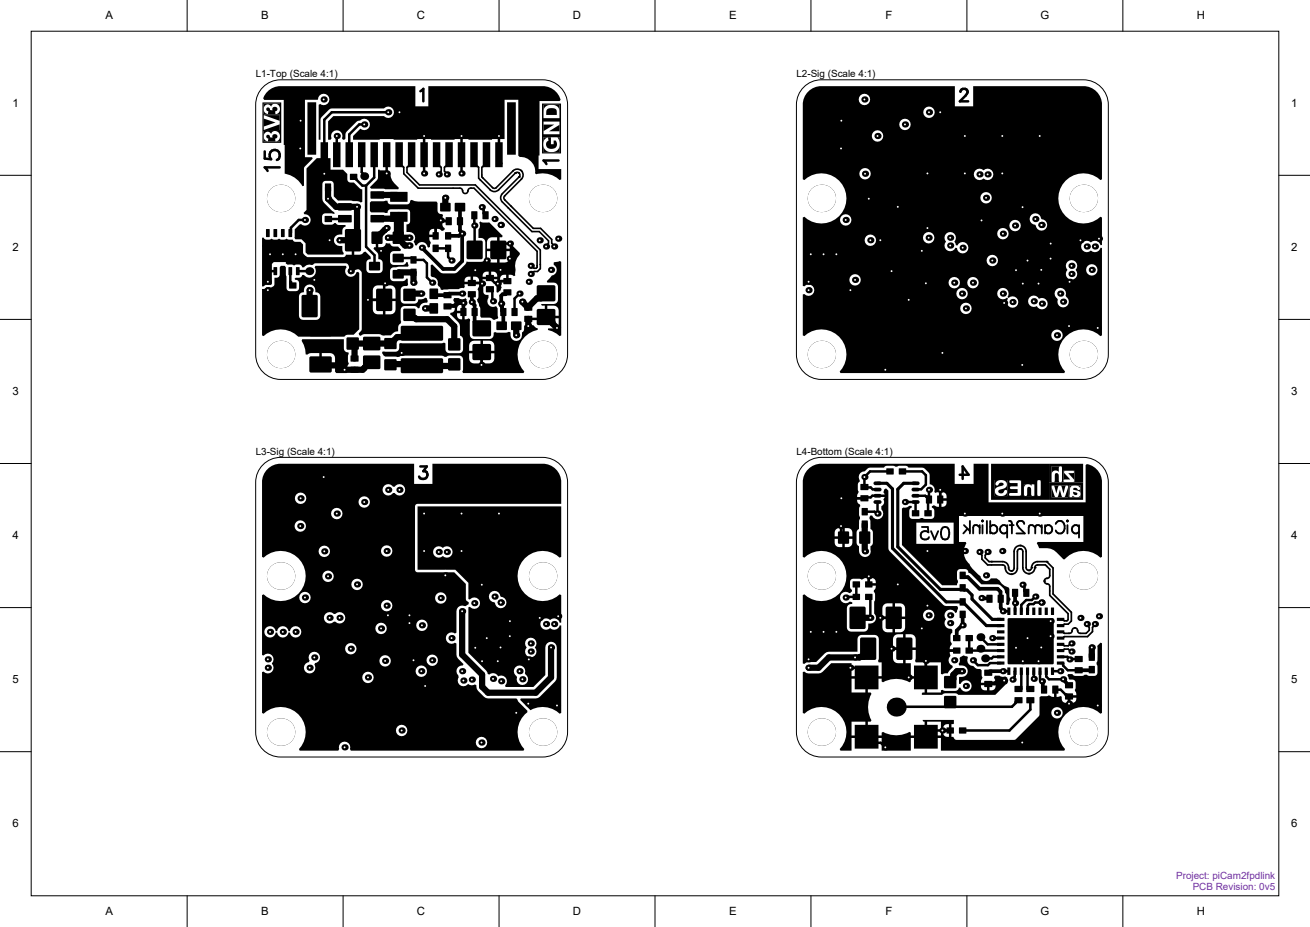
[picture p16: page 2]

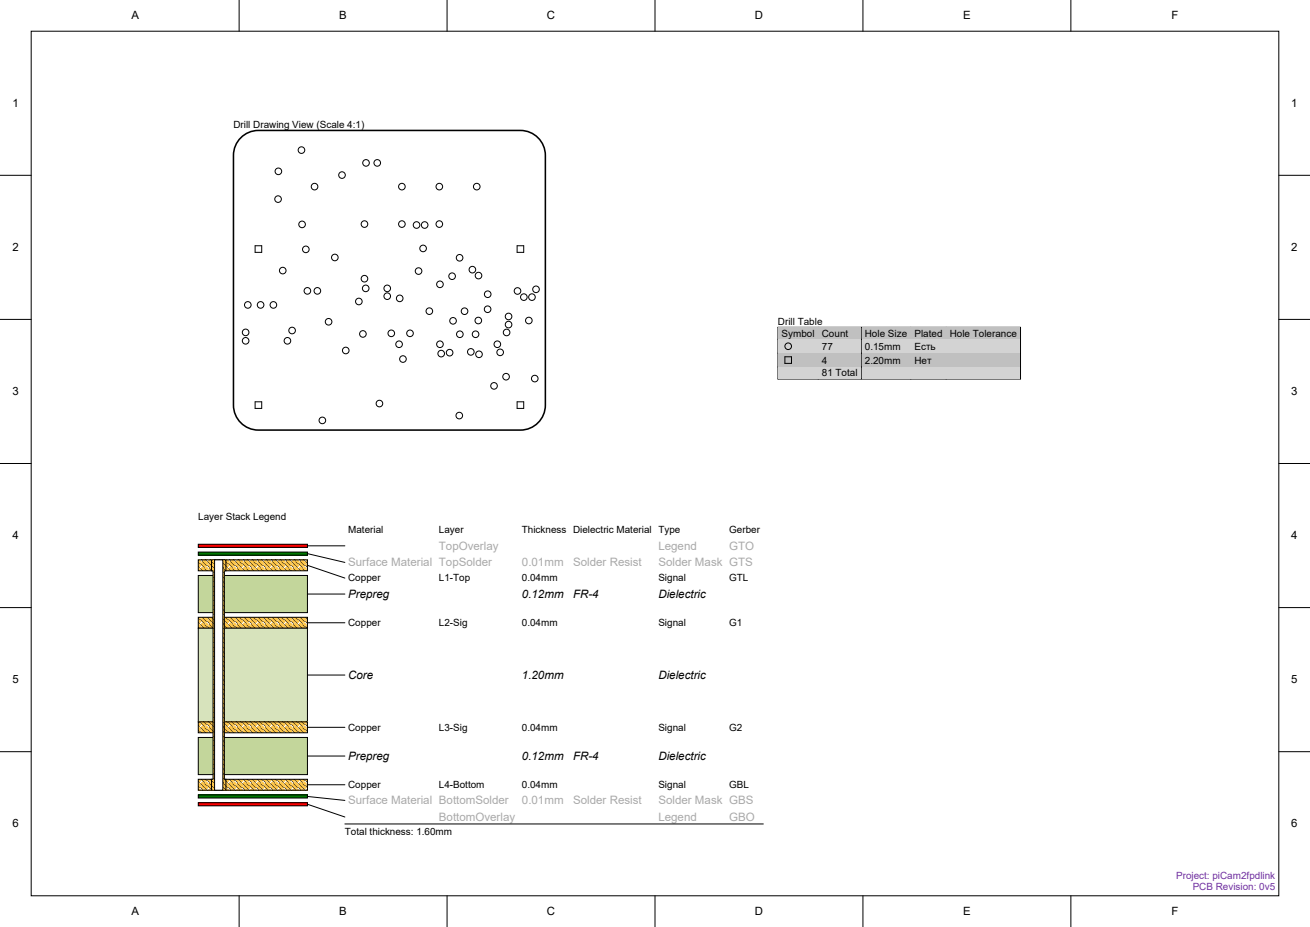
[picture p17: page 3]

Drill Drawing View (Scale 4:1)

Symbol | Count | Hole Size | Plated | Hole Tolerance

77 | 0.15mm | Есть
4 | 2.20mm | Нет
81 Total


View from Front side (Scale 7)

View from Back side (Scale 7)


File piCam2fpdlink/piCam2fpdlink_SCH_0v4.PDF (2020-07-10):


Rev | Date | Sign | Release Notes
0v0 0v1 0v2 0v3 0v4 | 06.11.19 22.04.20 27.04.20 30.04.20 05.05.20 | gana gana gana gana gana | 1st version for review purpose. Version with layout. Clean up library. Small changes and add BOM. L1 wrong footprint.

Zurich University of Applied Sciences
InES - Institute of Embedded Systems
P.O. Box, Technikumstrasse 9
8401 Winterthur
Switzerland

This document is property of InES - Institute of Embedded Systems

Size A3 | Document Number | Revision 0v4

Sheet 1 of 4 | Print date: 10.07.2020 | Drawn by: gana


JAC

V D DPL L_CA P

This document is propert

titute of Embedded Sy
Ins
writ

Siz e | Document Number | Revisio n v

Shee t 2 of | Print date: 10.07.20 | Drawn by : gana


This document is propert

titute of Embedded Sy
Ins
writ


This document is propert

titute of Embedded Sy
Ins
writ
